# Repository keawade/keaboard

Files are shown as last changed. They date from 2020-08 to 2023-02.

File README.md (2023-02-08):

# keaboard

A split ergo 4x6 keyboard designed by Keith Wade.

Designed for use with the [nice!nano][nicenanoDocs] USB-C Bluetooth Pro Micro replacement
but also works with any Pro Micro compatible controllers like the Elite-C.

Inspired by the [ErgoTravel][ergotravel] keyboard designed by @jpconstantineau.

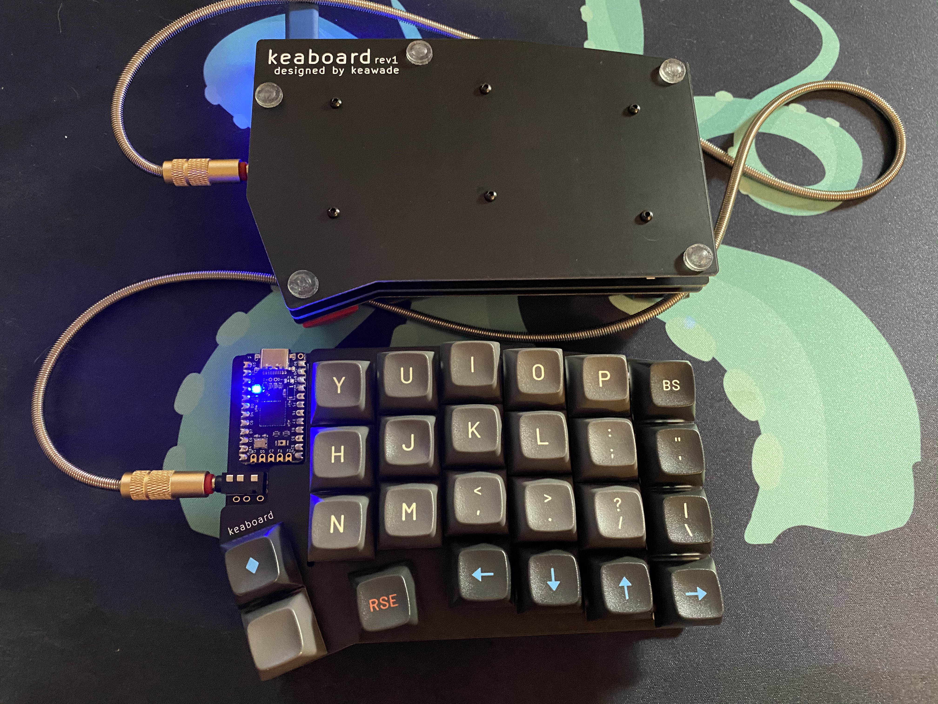
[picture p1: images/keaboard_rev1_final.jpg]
keaboard


## Primary Features

- Split
- Columnular stagger
- Wireless option
- Hot swap MX switches
- Reversible PCB

## Revision 1

### PCB

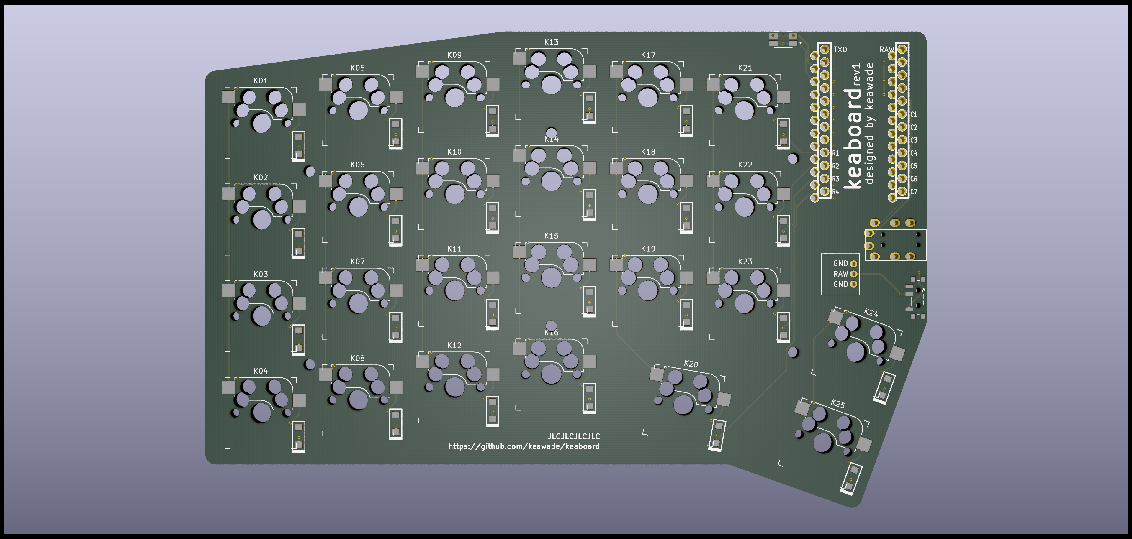
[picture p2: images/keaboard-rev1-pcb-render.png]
keaboard pcb render


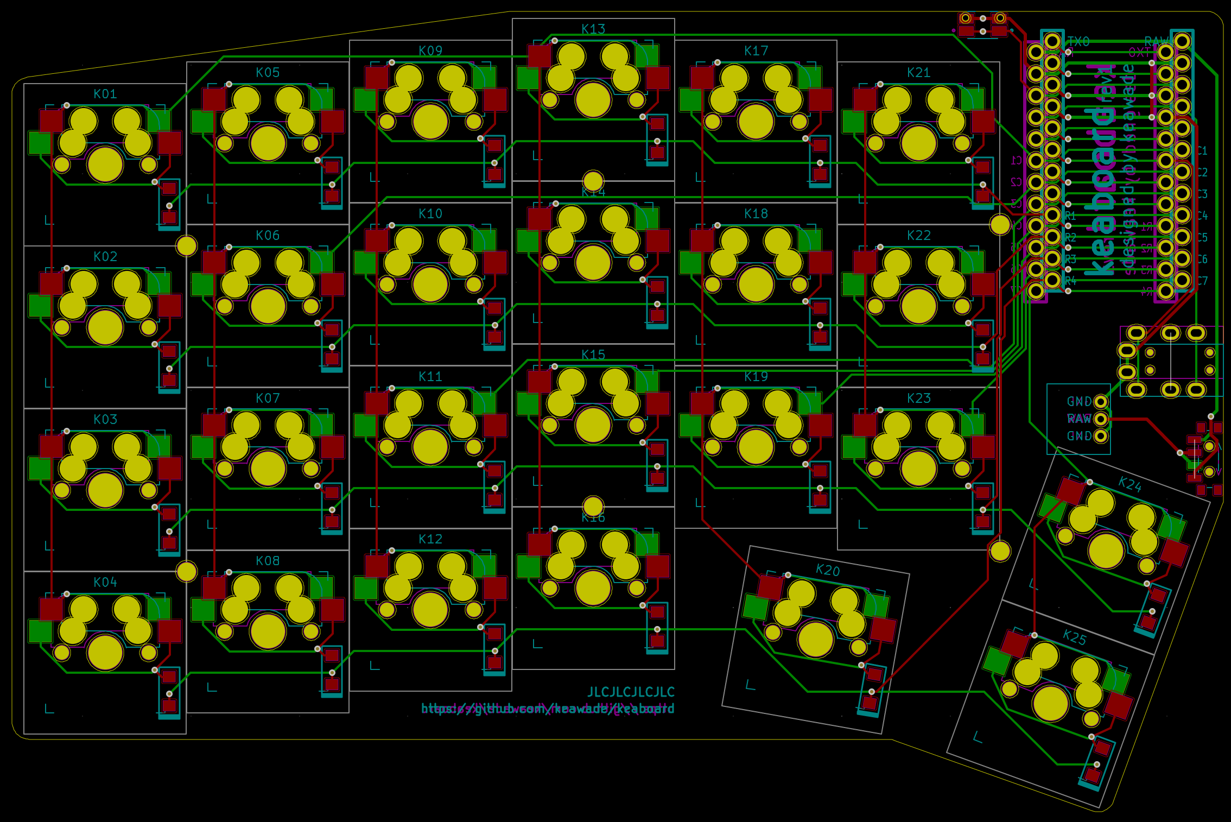
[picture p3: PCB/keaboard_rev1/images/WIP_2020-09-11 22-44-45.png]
keaboard pcb design


### PCB Case

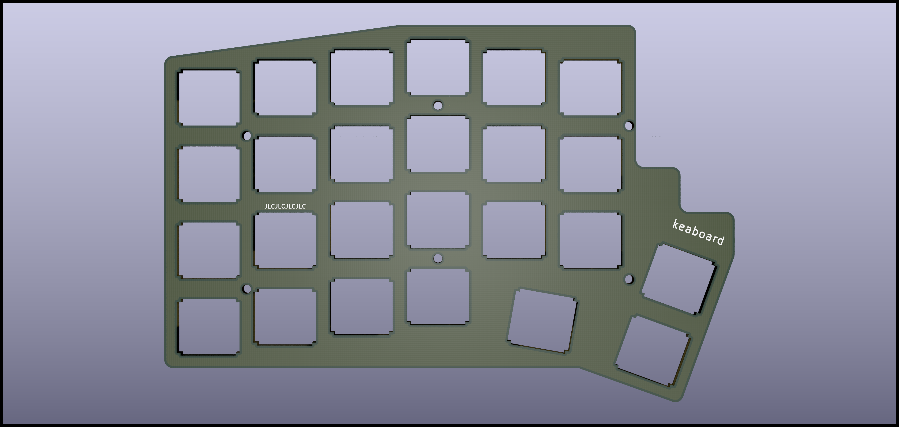
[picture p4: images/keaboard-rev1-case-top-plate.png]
Top plate


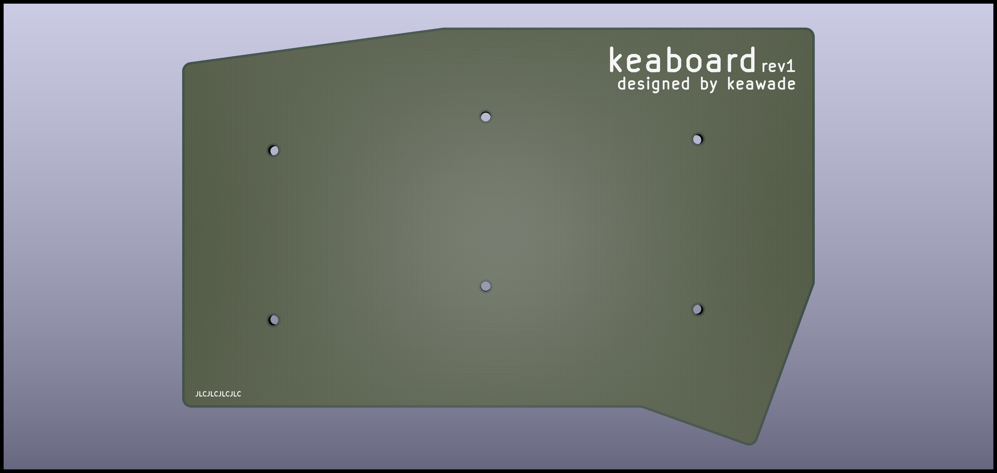
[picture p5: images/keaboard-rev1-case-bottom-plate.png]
Bottom plate


## Parts List

| Qty | Part |
| --- | --- |
| 2 | Pro Micro footprint compatible microcontroller (Recommend Elite-C if not using nice!nano) |
| 50 | MX compatible keyboard switches |  |
| 2 sets of 12 pins | Mill-Max low profile sockets |
| 24 (get extra though) | Mill-Max low profile pins |
| 50 | Kailh MX hot swap sockets |
| 50 | MX compatible switches |
| 50 | [1N4148W SMD diodes][diodes] |
| 2 | PJ-320A TRRS female jack  (not required if wireless with nice!nano) |
| 2 | [EVQ-9P701P tactile switch](resetSwitch) |
| 24 | M2 x 4 mm screws |
| 12 | M2 x 7mm stand offs |

### Parts for Wireless Option

| Qty | Part |
| --- | --- |
| 2 | [nice!nano][nicenanoStore] |
| 2 | [CUS-12TB][slideSwitch] for power switch |
| 2 | 3.7v rechargeable battery |
| 2 | [3-pin socket][batterySocket] (Can solder directly if preferred) |
| 2 | 2-pin plug |

## Firmware

- [QMK Firmware][keaboardQmk]
- [ZMK Firmware][keaboardZmk]

## Potential Future Revisions

- Choc hot swap
- RGB underglow
- LED backlight
- RGB backlight
- Design case for either 3D printing or CNC

[nicenanoDocs]: https://docs.nicekeyboards.com/#/nice!nano/
[nicenanoStore]: https://splitkb.com/collections/keyboard-parts/products/nice-nano-rev1-0
[ergotravel]: https://github.com/jpconstantineau/ErgoTravel
[batterySocket]: https://www.digikey.com/product-detail/en/DF3A-3P-2DS/H3894-ND/560460
[diodes]: https://www.digikey.com/product-detail/en/1N4148W-G+RHG/1N4148W-GRHGCT-ND/7644279
[slideSwitch]: https://www.digikey.com/product-detail/en/nidec-copal-electronics/CUS-12TB/563-1102-1-ND/1124231
[resetSwitch]: https://www.digikey.com/product-detail/en/panasonic-electronic-components/EVQ-9P701P/P19095CT-ND/5872974
[keaboardQmk]: https://github.com/keawade/qmk_firmware/tree/keaboard
[keaboardZmk]: https://github.com/keawade/keaboard-zmk-config

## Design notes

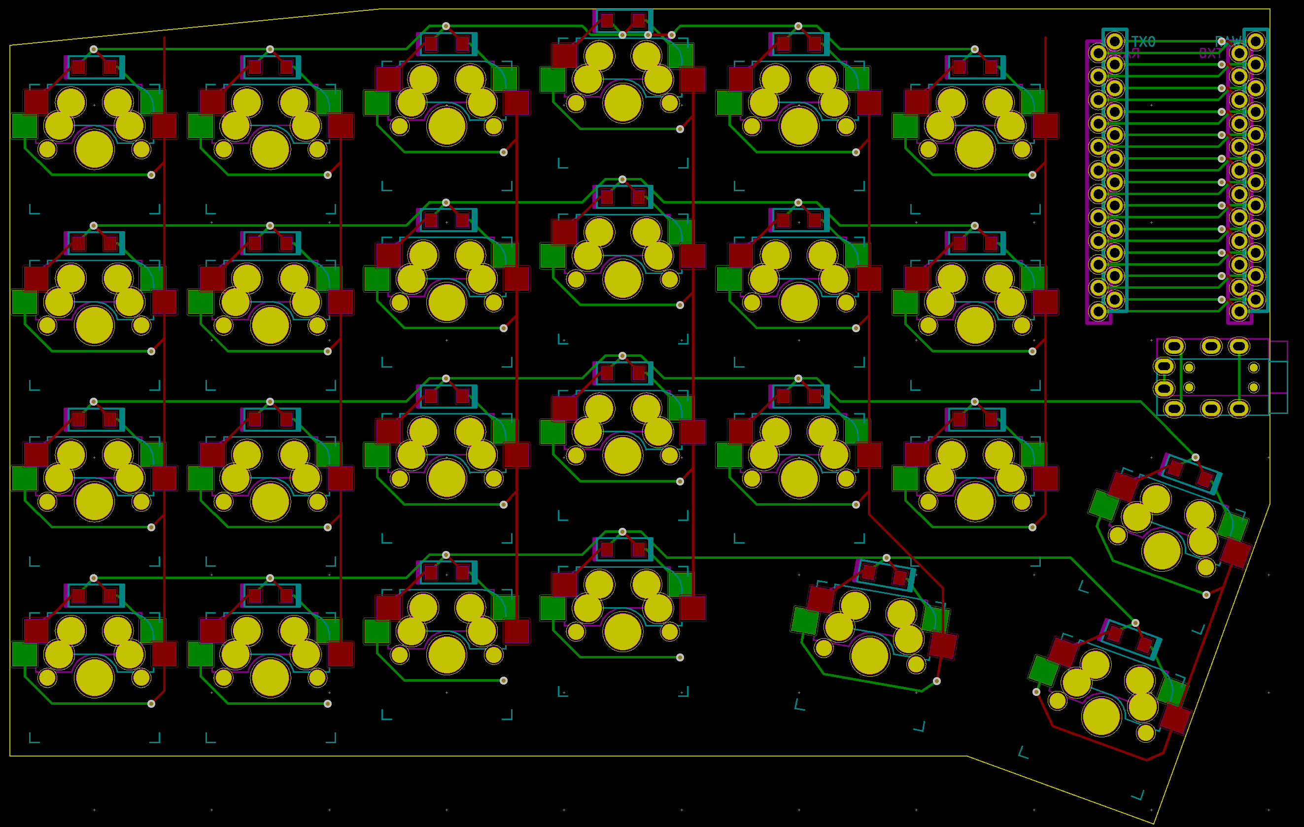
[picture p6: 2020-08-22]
PCB/keaboard_rev1/images/WIP_2020-08-22 17-29-02.png

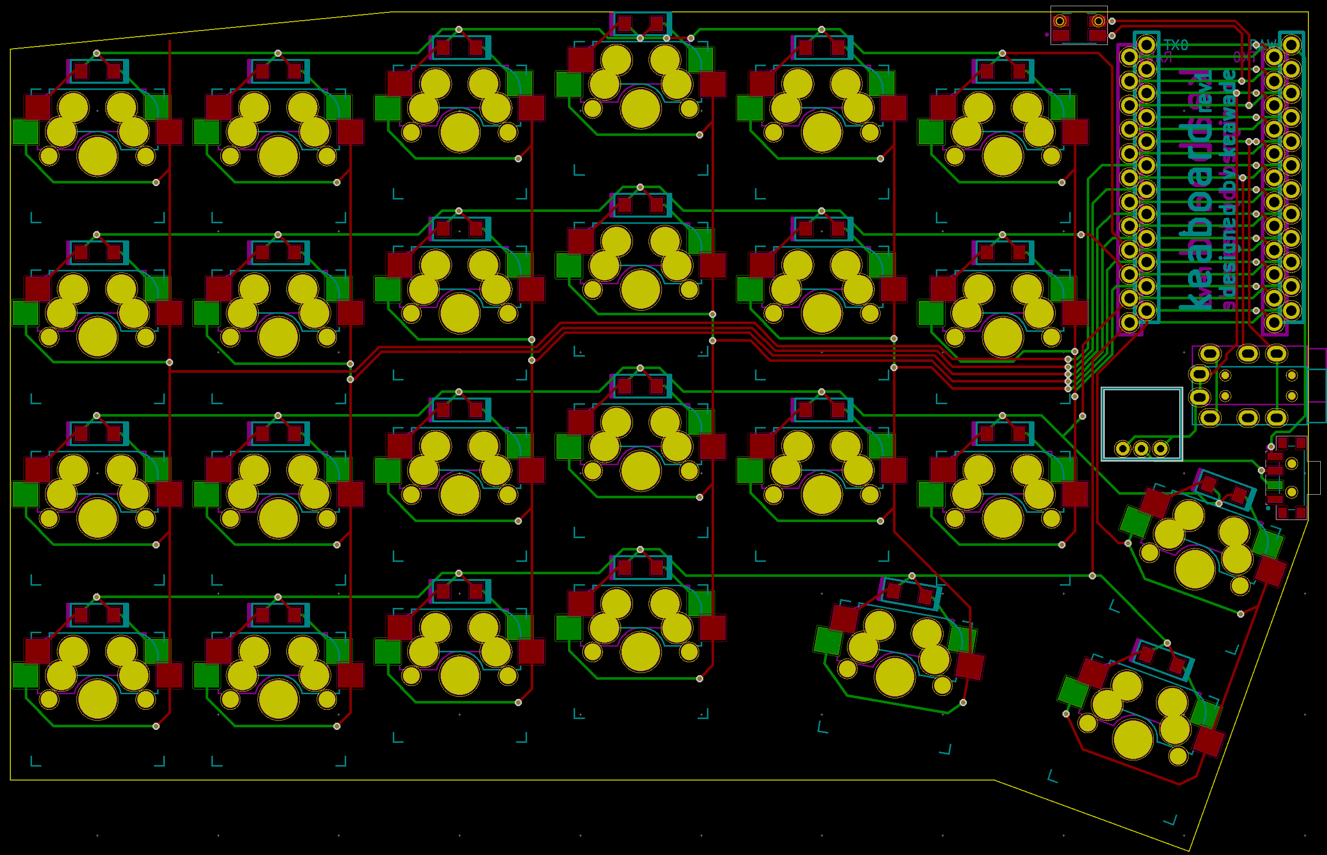
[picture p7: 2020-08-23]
PCB/keaboard_rev1/images/WIP_2020-08-22 23-34-56.png

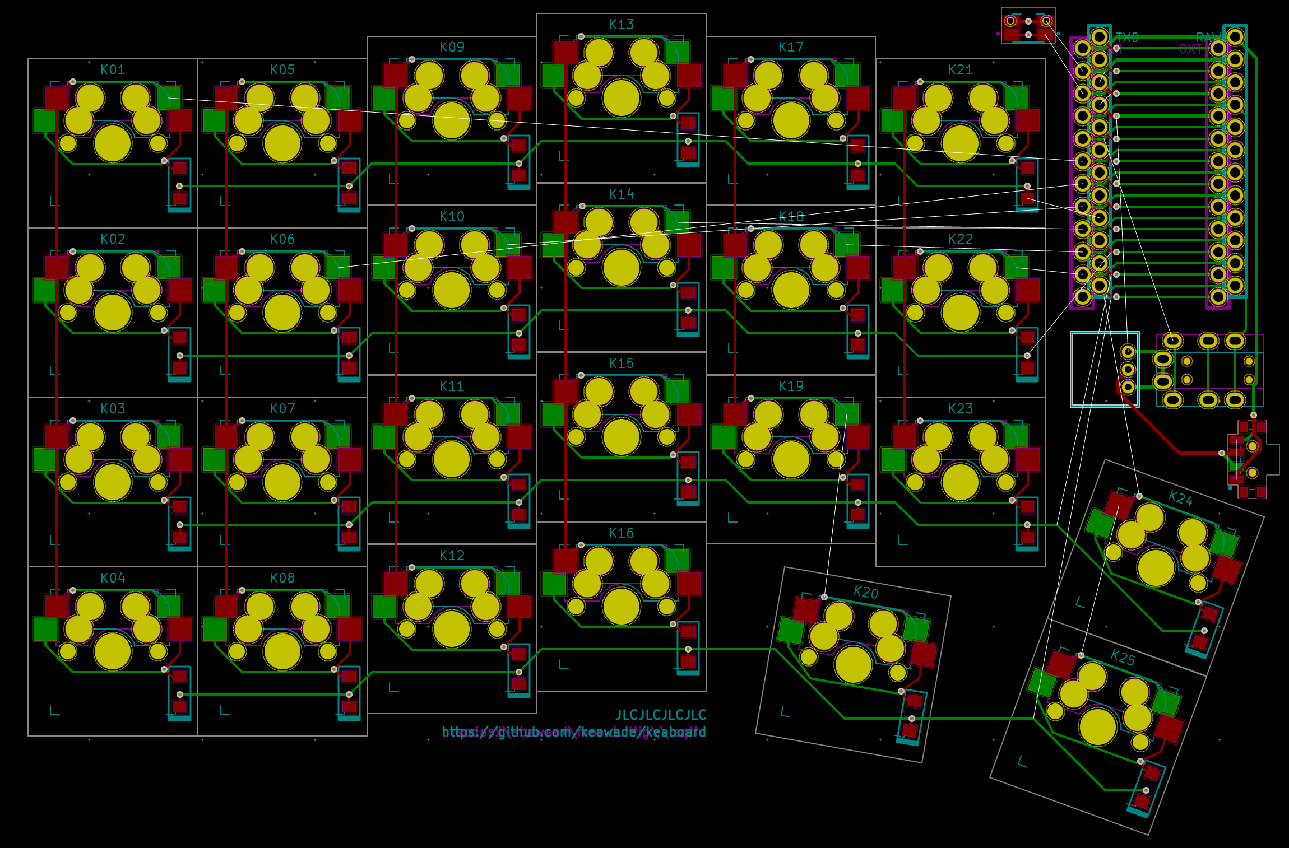
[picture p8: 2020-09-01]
PCB/keaboard_rev1/images/WIP_2020-08-31 22-45-34.png

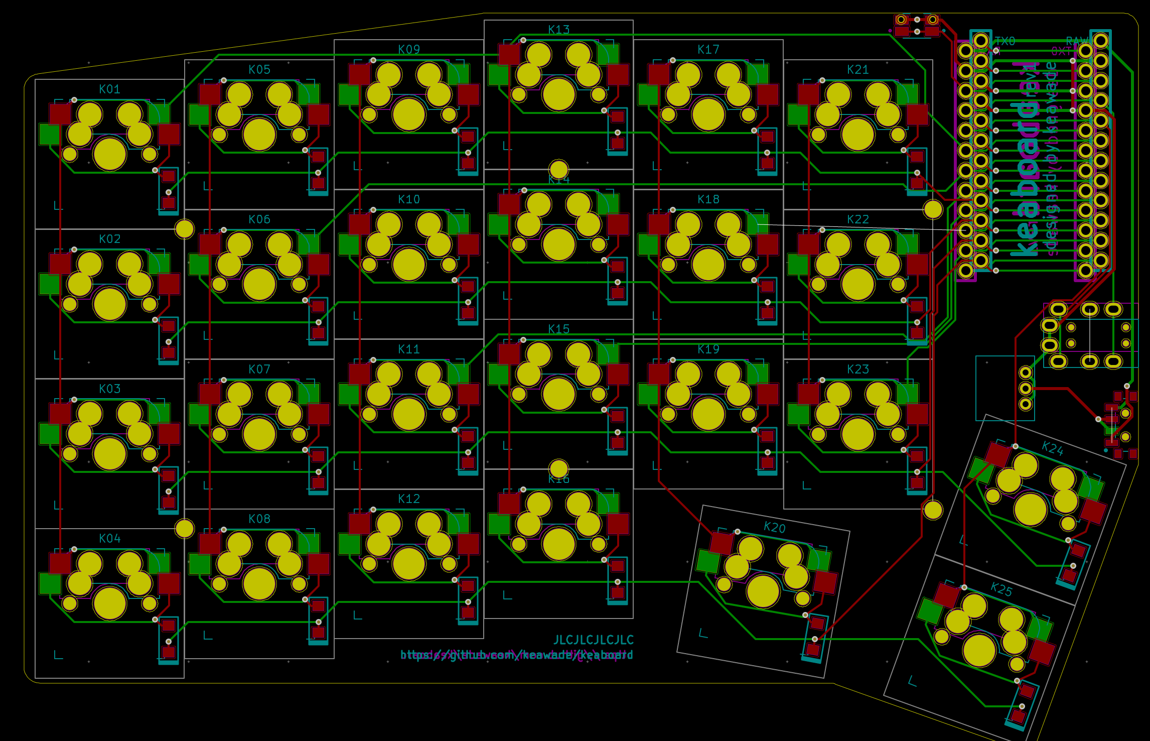
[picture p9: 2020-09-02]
PCB/keaboard_rev1/images/WIP_2020-09-01 20-43-06.png

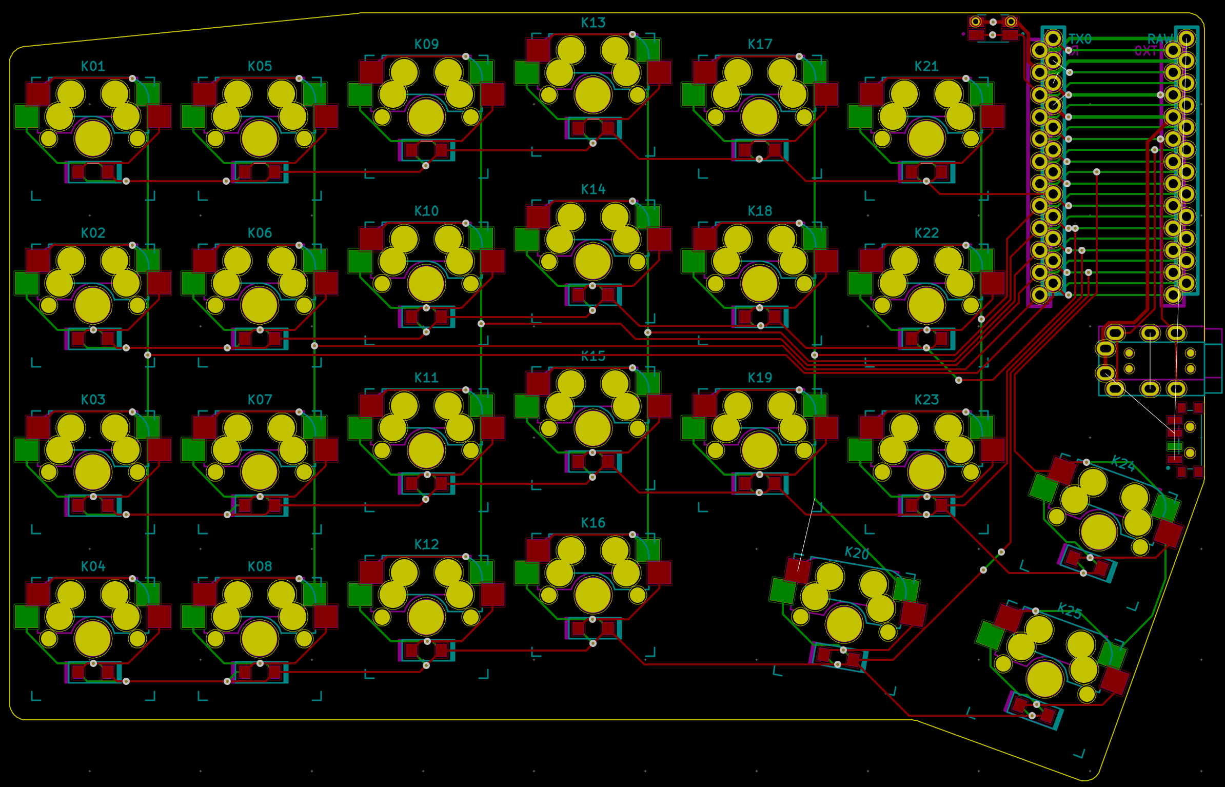
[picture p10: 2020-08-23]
PCB/keaboard_rev1/images/WIP_2020-08-23 14-30-25.png

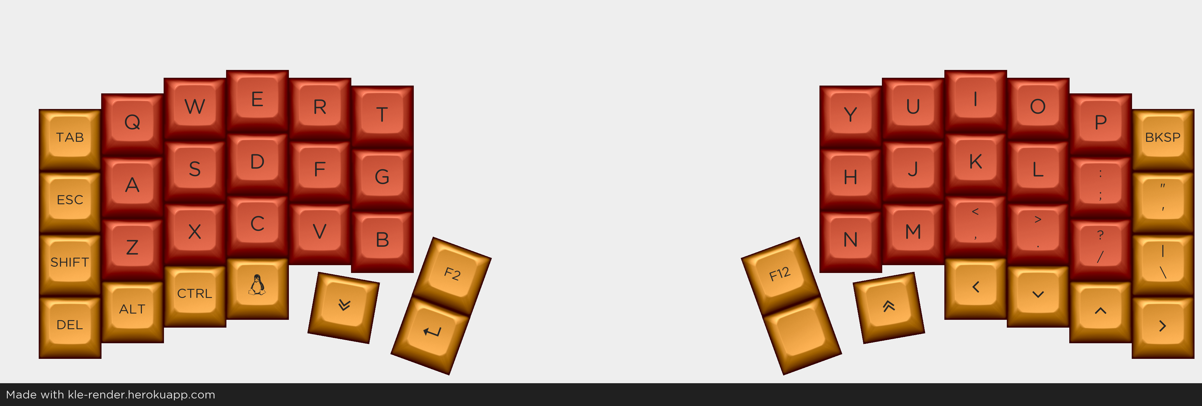
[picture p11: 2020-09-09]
images/keaboard-rev1-layout.png

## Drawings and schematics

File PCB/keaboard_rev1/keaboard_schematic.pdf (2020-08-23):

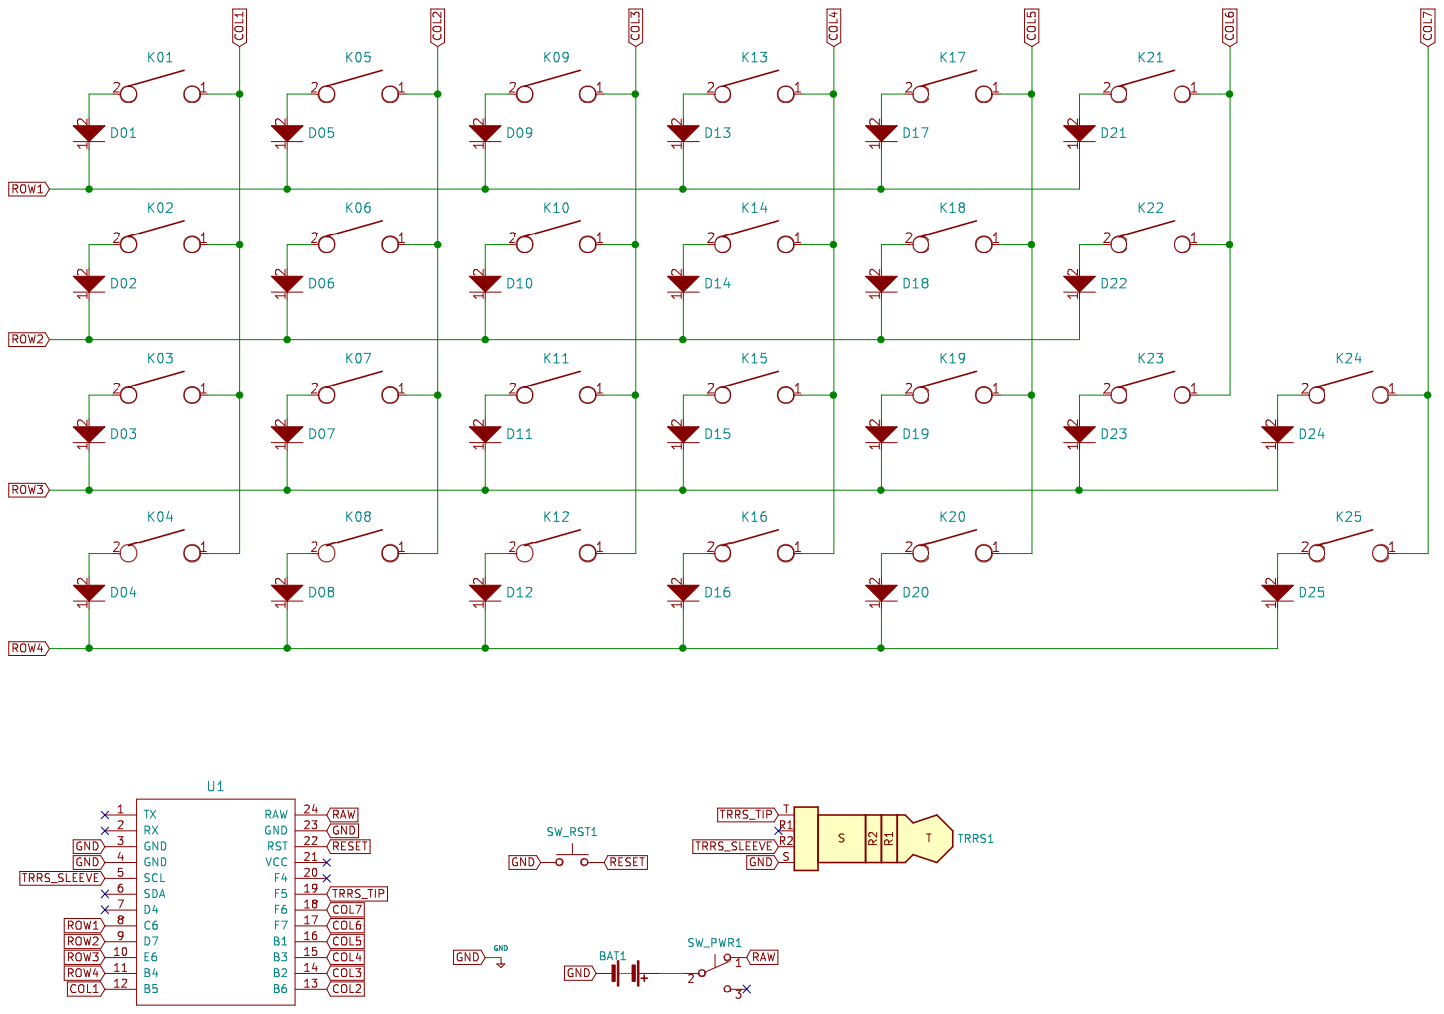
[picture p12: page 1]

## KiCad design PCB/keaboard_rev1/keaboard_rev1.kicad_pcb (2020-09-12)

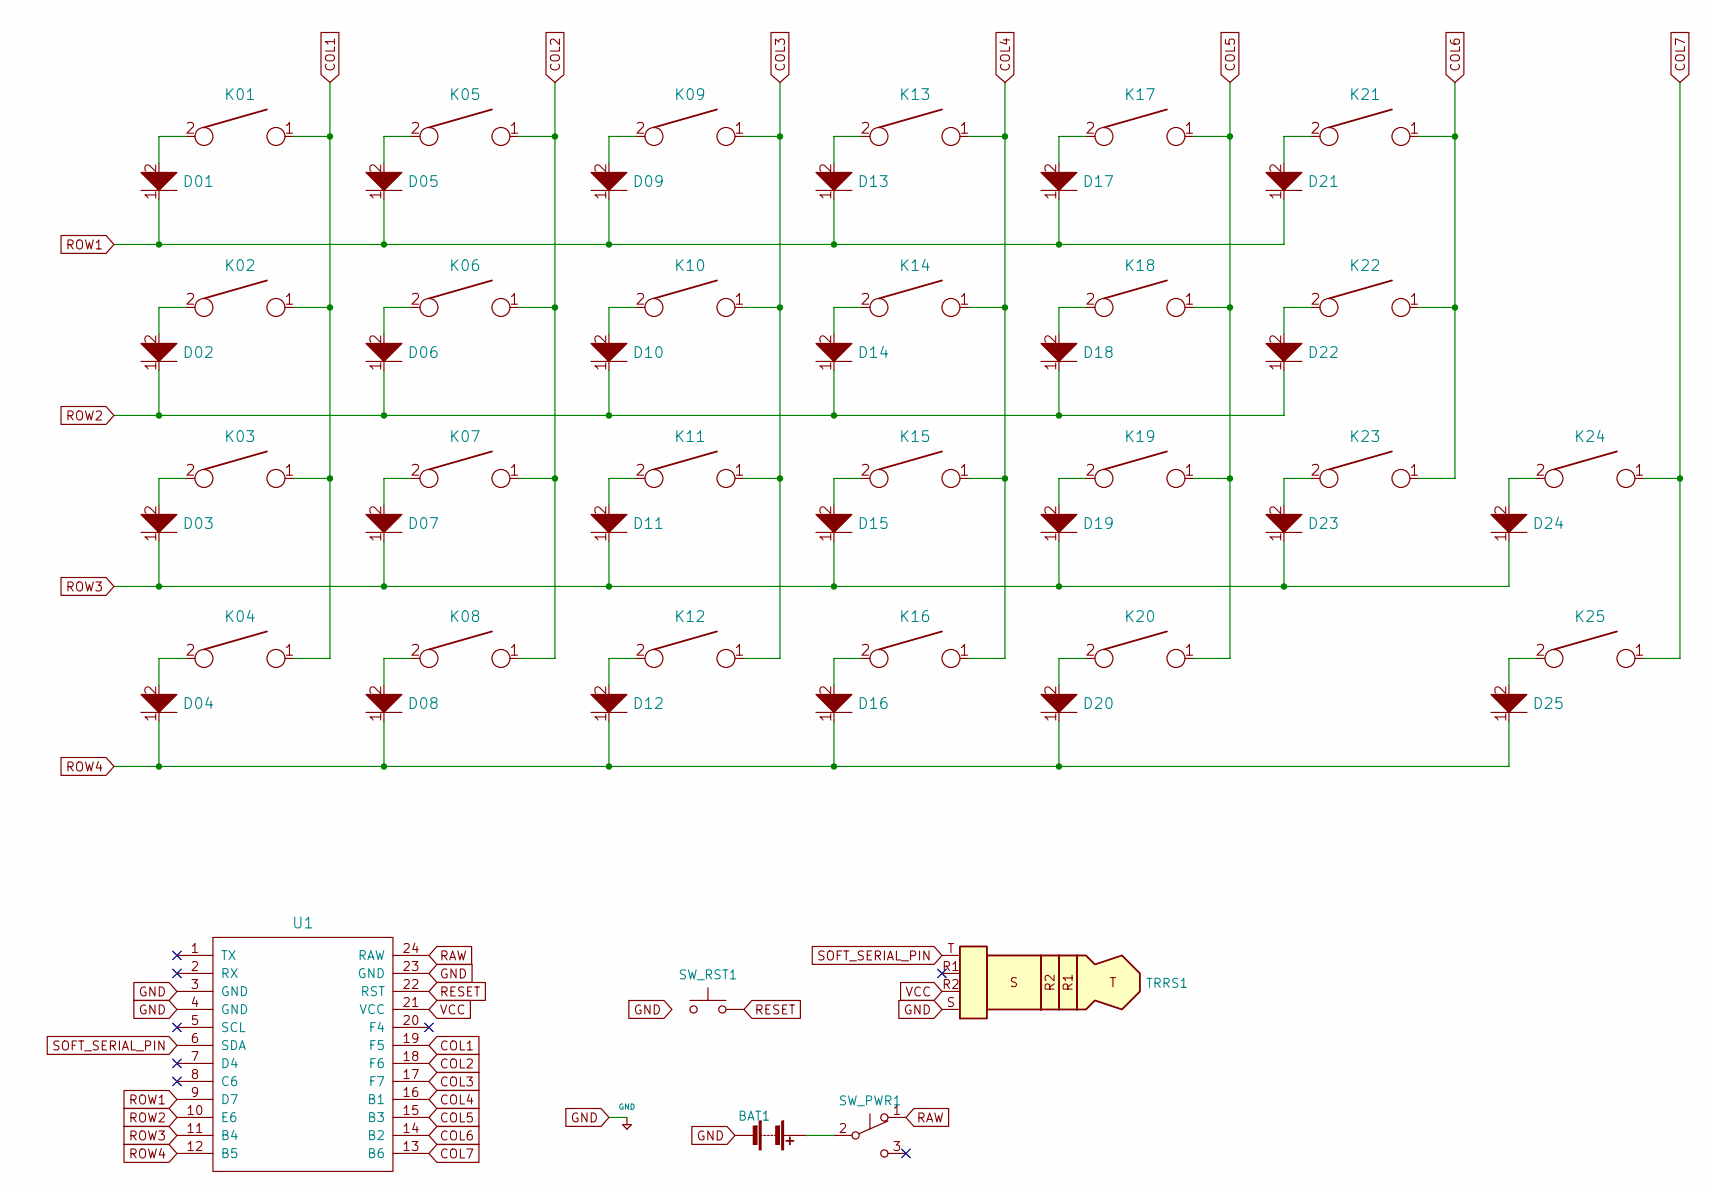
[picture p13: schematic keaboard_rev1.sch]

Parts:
BAT1: Battery; DF3A-3P-2DS_reversible
D01, D02, D03, D04, D05, D06, D07, D08, D09, D10, D11, D12, D13, D14, D15, D16, D17, D18, D19, D20, D21, D22, D23, D24, D25: D; D_SOD123_reversible
K01, K02, K03, K04, K05, K06, K07, K08, K09, K10, K11, K12, K13, K14, K15, K16, K17, K18, K19, K20, K21, K22, K23, K24, K25: KEYSW; Kailh_socket_MX_reversible
SW_PWR1: SW_Push_SPDT; SW_PCM12SMTR_reversible
SW_RST1: SW_EVQ-9P701P; SW_EVQ-9P701P_reversible
TRRS1: TRRS Jack; TRRS-PJ-320A_reversible
U1: ProMicro; ArduinoProMicro_Reversible

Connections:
COL1: K01.1, K02.1, K03.1, K04.1, U1.19 (F5)
COL2: K05.1, K06.1, K07.1, K08.1, U1.18 (F6)
COL3: K09.1, K10.1, K11.1, K12.1, U1.17 (F7)
COL4: K13.1, K14.1, K15.1, K16.1, U1.16 (B1)
COL5: K17.1, K18.1, K19.1, K20.1, U1.15 (B3)
COL6: K21.1, K22.1, K23.1, U1.14 (B2)
COL7: K24.1, K25.1, U1.13 (B6)
GND: BAT1.2 (-), SW_RST1.1 (A), SW_RST1.2 (A), TRRS1.S, U1.3 (GND), U1.4 (GND), U1.23 (GND)
unnamed: BAT1.1 (+), SW_PWR1.2 (B)
unnamed: D01.2, K01.2
unnamed: D02.2, K02.2
unnamed: D03.2, K03.2
unnamed: D04.2, K04.2
unnamed: D05.2, K05.2
unnamed: D06.2, K06.2
unnamed: D07.2, K07.2
unnamed: D08.2, K08.2
unnamed: D09.2, K09.2
unnamed: D10.2, K10.2
unnamed: D11.2, K11.2
unnamed: D12.2, K12.2
unnamed: D13.2, K13.2
unnamed: D14.2, K14.2
unnamed: D15.2, K15.2
unnamed: D16.2, K16.2
unnamed: D17.2, K17.2
unnamed: D18.2, K18.2
unnamed: D19.2, K19.2
unnamed: D20.2, K20.2
unnamed: D21.2, K21.2
unnamed: D22.2, K22.2
unnamed: D23.2, K23.2
unnamed: D24.2, K24.2
unnamed: D25.2, K25.2
RAW: SW_PWR1.1 (A), U1.24 (RAW)
RESET: SW_RST1.3 (B), SW_RST1.4 (B), U1.22 (RST)
ROW1: D01.1, D05.1, D09.1, D13.1, D17.1, D21.1, U1.9 (D7)
ROW2: D02.1, D06.1, D10.1, D14.1, D18.1, D22.1, U1.10 (E6)
ROW3: D03.1, D07.1, D11.1, D15.1, D19.1, D23.1, D24.1, U1.11 (B4)
ROW4: D04.1, D08.1, D12.1, D16.1, D20.1, D25.1, U1.12 (B5)
SOFT_SERIAL_PIN: TRRS1.T, U1.6 (SDA)
VCC: TRRS1.R2, U1.21 (VCC)

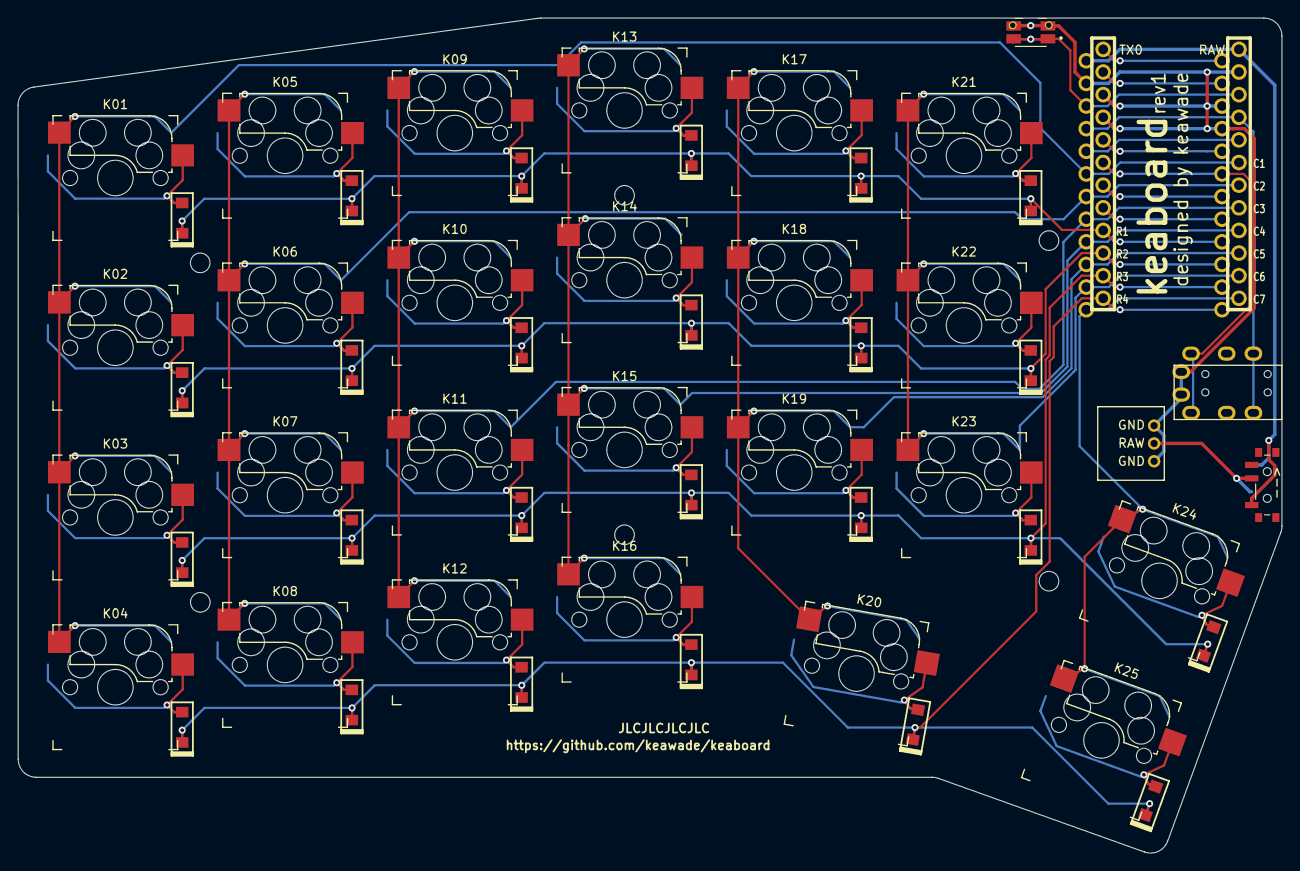
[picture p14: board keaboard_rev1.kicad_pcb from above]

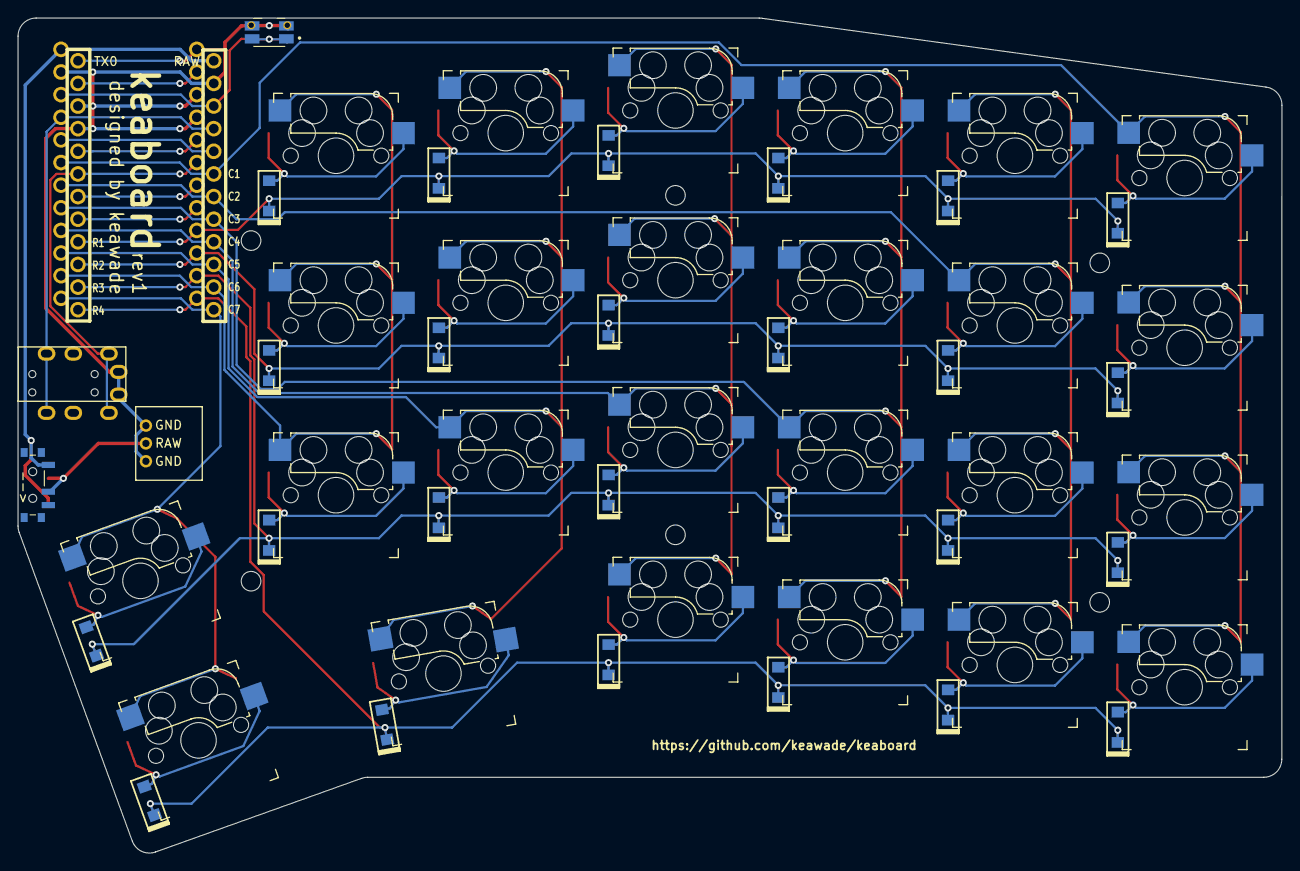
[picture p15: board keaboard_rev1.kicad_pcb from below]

Board: 2 copper layers, 141.9 x 93.7 mm, 55 parts (25 on the bottom side), 42 nets.

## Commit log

2020-06-19 Initialize KiCad project
    [keaboard.kicad_pcb, keaboard.sch]
2020-08-18 Flip sockets to correct side, adjust diode placement, place controller
    [keaboard.sch]
2020-08-18 Remove old kicad files
    [keaboard.kicad_pcb]
2020-08-19 Create KiCAD project
    [keaboard.kicad_pcb, keaboard.sch]
2020-08-20 Switch layout, diodes
    [keaboard.kicad_pcb]
2020-08-20 Add traces, add TRRS jack, add B+/B- pins, update README
    [keaboard.kicad_pcb]
2020-08-21 Connect matrix to data pins
    [keaboard.kicad_pcb]
2020-08-21 Minor rerouting, add reset switch, add edge cut
    [keaboard.kicad_pcb]
2020-08-21 Add keaboard label
    [keaboard.kicad_pcb]
2020-08-22 Add 3-pin JST connector, remove B+/B- pin holes
    [keaboard.kicad_pcb]
2020-08-22 Clean up kicad mod directories
2020-08-22 Reroute TRRS connection, reroute row connections, move progress images
    [keaboard.kicad_pcb]
2020-08-22 Remove old files
    [keaboard.kicad_pcb, keaboard.sch]
2020-08-22 Core reversible PCB designs
    [keaboard_rev1.kicad_pcb, keaboard_rev1.sch]
2020-08-22 Keyboard layout and cutout
    [keaboard_rev1.kicad_pcb]
2020-08-23 Add reset switch, add power switch, add docs
    [keaboard_rev1.kicad_pcb]
2020-08-23 Route traces for matrix
    [keaboard_rev1.kicad_pcb]
2020-08-23 Add label, update README
    [keaboard_rev1.kicad_pcb]
2020-08-23 WIP, created WIP reversible footprints, created schematic, updated board with schematic
    [keaboard_rev1.kicad_pcb]
2020-08-23 Footprints laid out from schematic
    [keaboard_rev1.kicad_pcb]
2020-08-23 Wired matrix
    [keaboard_rev1.kicad_pcb]
2020-08-23 Fix reset switch, wire reset switch, wire grounds
    [keaboard_rev1.kicad_pcb, keaboard_rev1.sch]
2020-08-23 Connect battery, fix unconnected lines
    [keaboard_rev1.kicad_pcb, keaboard_rev1.sch]
2020-08-23 Place label
    [keaboard_rev1.kicad_pcb]
2020-08-23 Move battery plug
    [keaboard_rev1.kicad_pcb]
2020-08-23 PDF schematic, add screw holes, update README
    [keaboard_rev1.kicad_pcb]
2020-08-23 Add labels to battery plug, update battery plug footprint to correctly map pin holes, reroute traces to battery plug
    [keaboard_rev1.kicad_pcb]
2020-08-23 Add 'on >' label on back the board relative to the switch
2020-08-23 Update pcb image, generate gerber
    [keaboard_rev1-B_Cu.gbr, keaboard_rev1-B_Mask.gbr, keaboard_rev1-B_SilkS.gbr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]
2020-08-23 Zip gerber
2020-08-23 Case top plate
    [keaboard_rev1.kicad_pcb, keaboard_rev1.sch]
2020-08-23 TopPlate and BottomPlate
    [BottomPlate.kicad_pcb, BottomPlate.sch, TopPlate.kicad_pcb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]
2020-08-23 Generate and zip gerber for plates
    [BottomPlate-B_Cu.gbr, BottomPlate-B_Mask.gbr, BottomPlate-B_SilkS.gbr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]
2020-08-25 Add pcb render to readme
2020-08-25 Resize PCB to add more space around the edges to avoid breaking parts, update images, update gerber
    [BottomPlate-B_Cu.gbr, BottomPlate-B_Mask.gbr, BottomPlate-B_Paste.gbr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]
2020-08-25 Organize images, add top/bottom plate renders
2020-09-01 Update schematic, update footprints, start updating layout
    [keaboard_rev1.kicad_pcb, keaboard_rev1.sch]
2020-09-02 Update cases, update edge cuts on main pcb, start routing traces to controller
    [BottomPlate.kicad_pcb, TopPlate.kicad_pcb, keaboard_rev1.kicad_pcb]
2020-09-02 Route traces, add labels
    [TopPlate.kicad_pcb, keaboard_rev1.kicad_pcb]
2020-09-02 Update gerber
    [BottomPlate-B_Cu.gbr, BottomPlate-B_Mask.gbr, BottomPlate-B_Paste.gbr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]
2020-09-02 Remove switch numbering from top plate
    [TopPlate-B_Cu.gbr, TopPlate-B_Mask.gbr, TopPlate-B_Paste.gbr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]
2020-09-02 Fix missing trace
    [keaboard_rev1-B_Cu.gbr, keaboard_rev1-B_Mask.gbr, keaboard_rev1-B_Paste.gbr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]
2020-09-08 Update schematic, TODO: Update pcb
    [keaboard_rev1.sch]
2020-09-09 Update PCB to fix incorrect trace
    [keaboard_rev1-B_Cu.gbr, keaboard_rev1-B_Mask.gbr, keaboard_rev1-B_Paste.gbr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]
2020-09-12 Improve labeling
    [keaboard_rev1-B_Cu.gbr, keaboard_rev1-B_Mask.gbr, keaboard_rev1-B_Paste.gbr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]
2020-09-23 Update to image of final board
